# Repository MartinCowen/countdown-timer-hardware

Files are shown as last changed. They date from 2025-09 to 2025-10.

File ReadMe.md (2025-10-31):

# Child-friendly Countdown Timer  
Electronic PCB and Front Panel to fit Hammond RL6655, designed in Kicad 9.0

## Main components
 - STM32C031C6: Cortex-M0+, 32kB flash, 12kB RAM, 45 IOs
 - 0.8 inch 7-segment displays SA08-11SURKWA
 - C&K D6 buttons
 - USB micro powered from a battery pack, 0.6mA in sleep.

## PCB parameters
Two layers, mix of surface mount and through hole components, ground plane fill.

## Bill of Materials
SMT Part numbers for LCSC (JLC) 
Through hole, SMTs not available at LCSC and mechanical parts from RS or Mouser.

## Front Panel
PCB with black solder mask, white silkscreen, cutouts for displays, LEDs, buttons, mounting holes. Replaces front panel on RL6655, main PCB is mounted behind it.

## Additional components needed
 - Either a 5V 0.5A PSU (phone charger) or portable battery with USB output
 - USB A to USB micro short cable for the portable battery
 - Cable ties to hold battery back to back of PCB
 - optional: Display filter material, 40x100mm, < 1mm thick.
 - for programming: STLINK-V3MINIE with ribbon cable from [STM32C0316-DK](https://www.st.com/en/evaluation-tools/stm32c0316-dk.html)
 - for programming: USB C cable to your laptop (USB C or USB A) from the STLINK

## Firmware
[Firmware in C for STM32C031C6](https://github.com/MartinCowen/countdown-timer-firmware) built in STM32CubeIDE

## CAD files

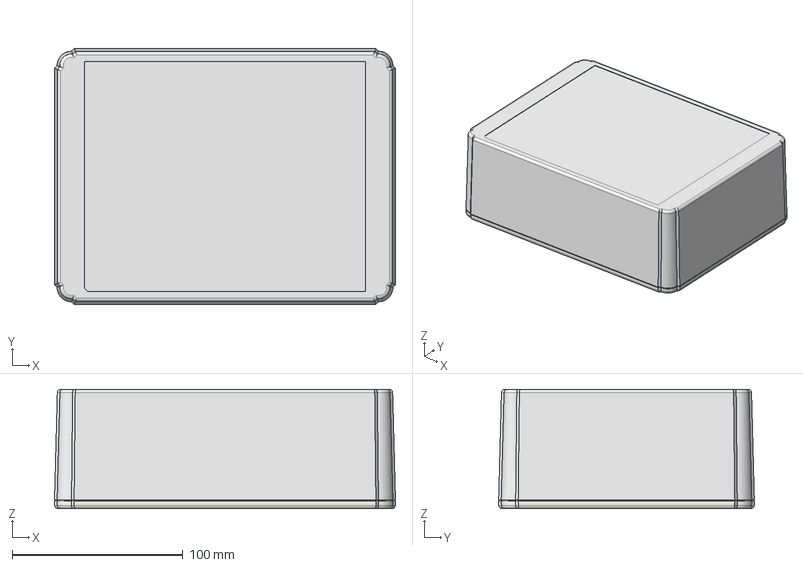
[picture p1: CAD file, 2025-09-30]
frontpanel_pcb/RL6655.stp
200.0 x 150.0 x 70.0 mm
6655B
(screw M2.6X 20mm FH) x 4

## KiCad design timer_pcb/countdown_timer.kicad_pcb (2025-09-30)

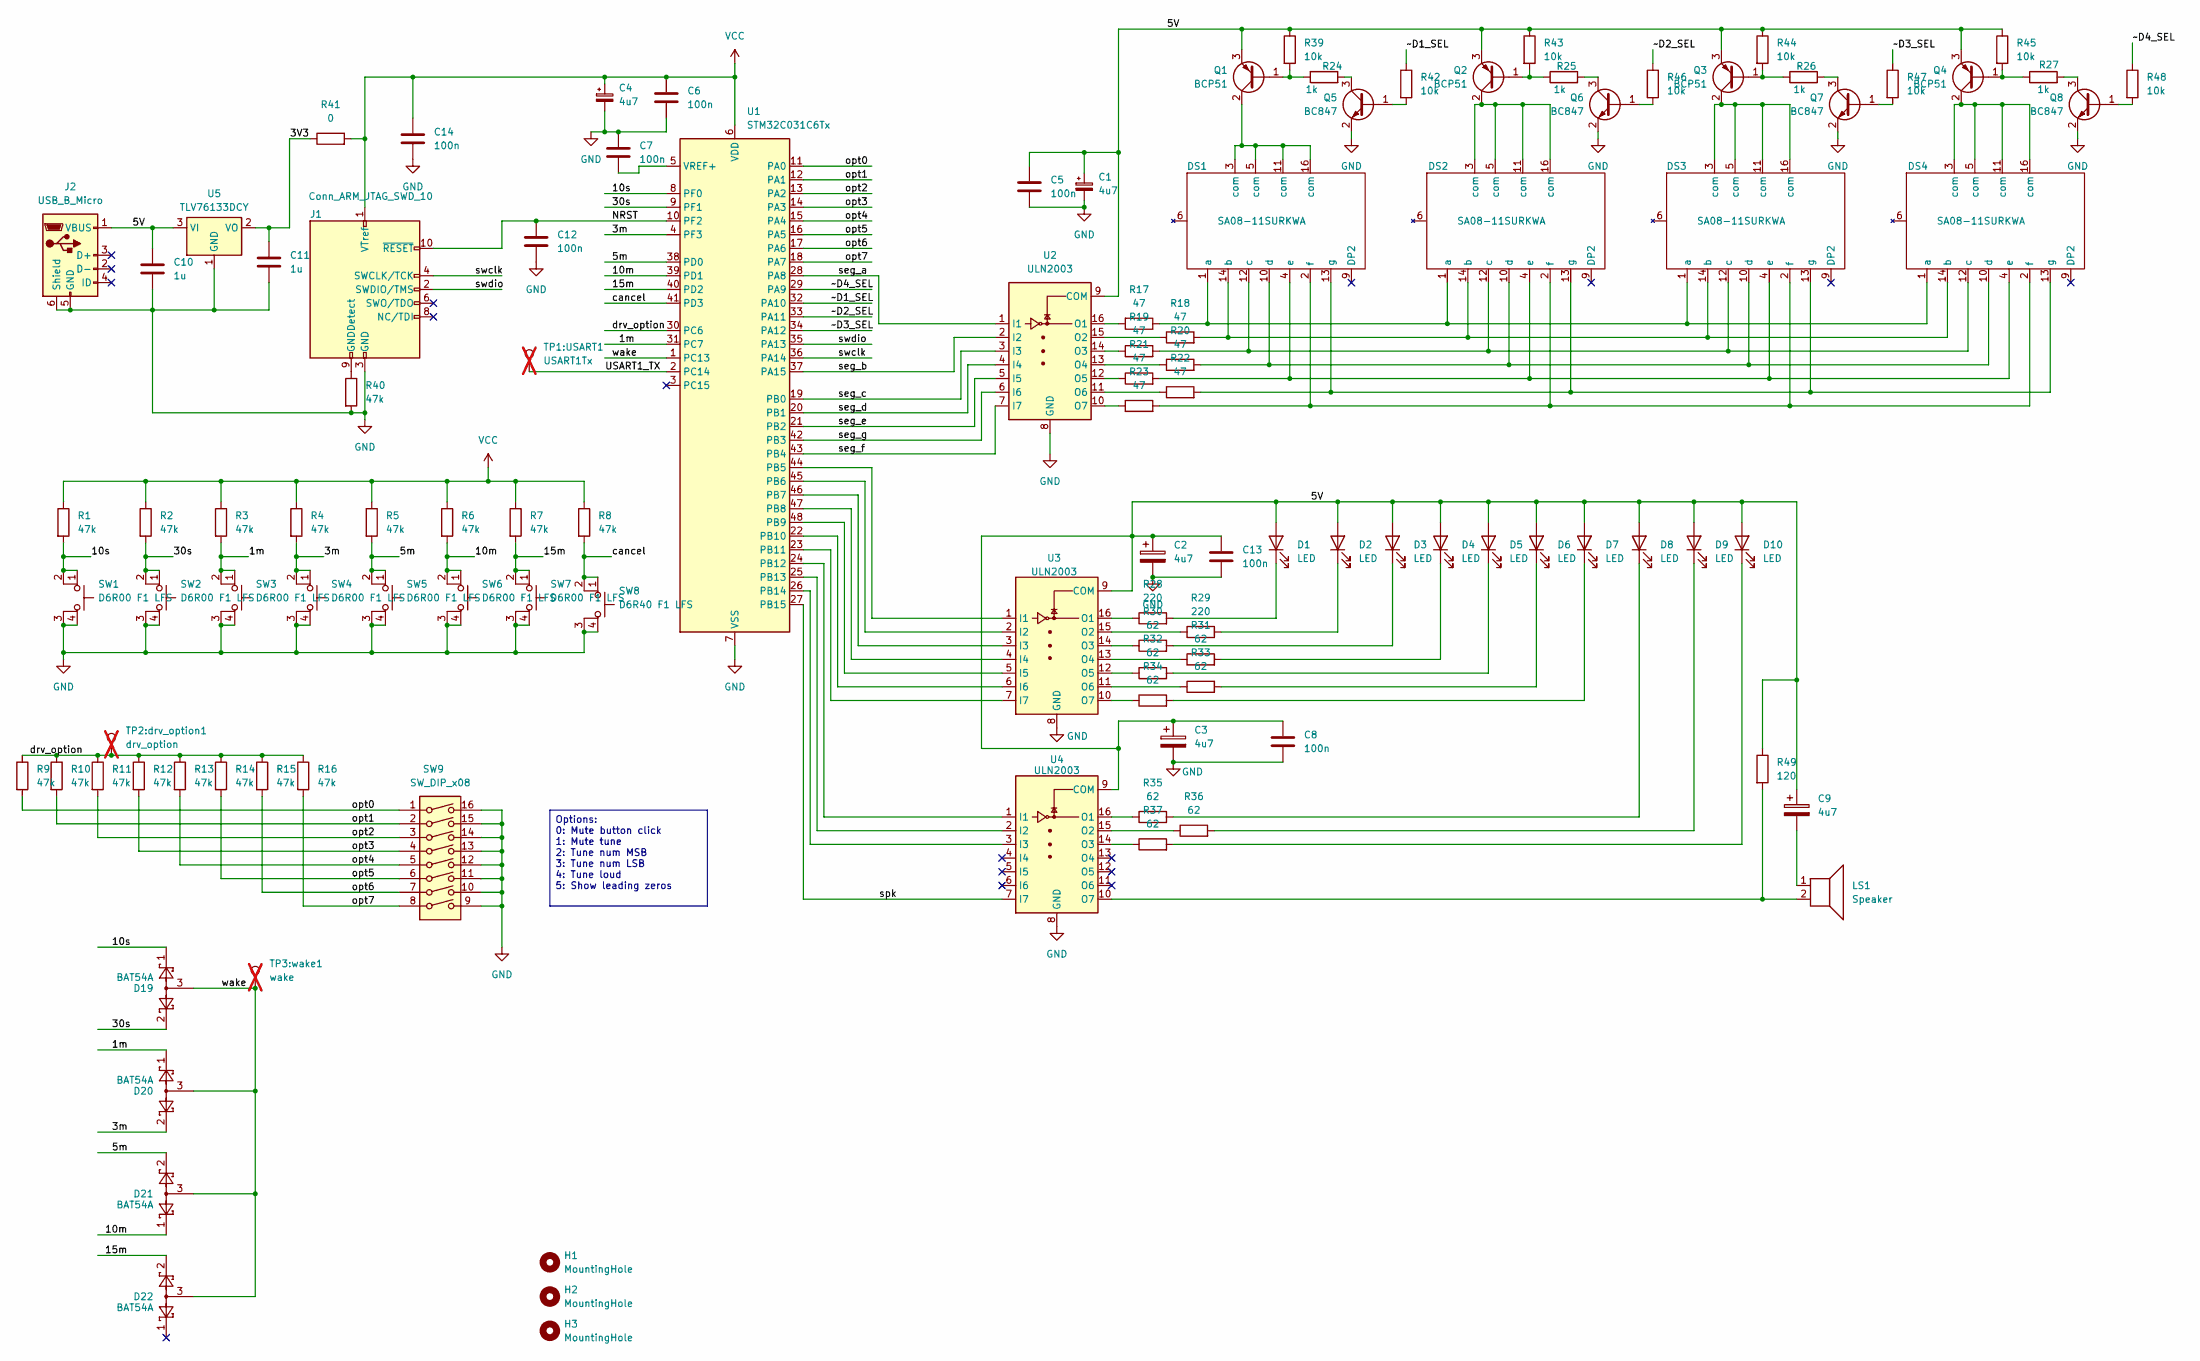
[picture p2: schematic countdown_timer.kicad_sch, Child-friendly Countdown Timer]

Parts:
C1, C2, C3, C4, C9: 4u7; CP_Elec_4x5.4; LCSC C59949
C5, C6, C7, C8, C12, C13, C14: 100n; C_0805_2012Metric; LCSC C49678
C10, C11: 1u; C_0805_2012Metric; LCSC C24123
D1, D2, D3, D4, D5, D6, D7, D8, D9, D10: LED; LED_D5.0mm_FlatTop; LCSC DNP
D19, D20, D21, D22: BAT54A; SOT-323_SC-70; LCSC C77317
DS1, DS2, DS3, DS4: SA08-11SURKWA; LCSC DNP
H1, H2, H3: MountingHole; ToolingHole_1.152mm; LCSC DNP
J1: Conn_ARM_JTAG_SWD_10; PinHeader_2x05_P1.27mm_Vertical_SMD; LCSC C5155080
J2: USB_B_Micro; USB_Micro-B_Amphenol_10118194-0001LF_Horizontal; LCSC C132563
LS1: Speaker; CMS-151504-SMT-TR; LCSC DNP
Q1, Q2, Q3, Q4: BCP51; SOT-223-3_TabPin2; LCSC C41375111
Q5, Q6, Q7, Q8: BC847; SOT-323_SC-70; LCSC C8659
R1, R2, R3, R4, R5, R6, R7, R8, R9, R10, R11, R12, R13, R14, R15, R16, R40: 47k; R_0805_2012Metric; LCSC C17713
R17, R18, R19, R20, R21, R22, R23: 47; R_0805_2012Metric; LCSC C17714
R24, R25, R26, R27: 1k; R_0805_2012Metric; LCSC C17513
R28, R29: 220; R_0805_2012Metric; LCSC C17557
R30, R31, R32, R33, R34, R35, R36, R37: 62; R_0805_2012Metric; LCSC C17557
R39, R42, R43, R44, R45, R46, R47, R48: 10k; R_0805_2012Metric; LCSC C17414
R41: 0; R_0805_2012Metric; LCSC C17477
R49: 120; R_0805_2012Metric; LCSC C17437
SW1, SW2, SW3, SW4, SW5, SW6, SW7: D6R00 F1 LFS; CK_D6; LCSC C221608
SW8: D6R40 F1 LFS; CK_D6; LCSC C668538
SW9: SW_DIP_x08; DIP-16_W7.62mm; LCSC C108707
TP1:USART1: USART1Tx; TestPoint_Pad_D1.5mm; LCSC DNP; not fitted
TP2:drv_option1: drv_option; TestPoint_Pad_D1.5mm; LCSC DNP; not fitted
TP3:wake1: wake; TestPoint_Pad_D1.5mm; LCSC DNP; not fitted
U1: STM32C031C6Tx; LQFP-48_7x7mm_P0.5mm; LCSC C5456218
U2, U3, U4: ULN2003; SOIC-16_3.9x9.9mm_P1.27mm; LCSC C7512
U5: TLV76133DCY; SOT-223-3_TabPin2; LCSC C7527500

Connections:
/1m: D20.1, R3.2, SW3.1, SW3.2, U1.31 (PC7)
/3V3: C11.1, R41.1, U5.2 (VO)
/3m: D20.2, R4.2, SW4.1, SW4.2, U1.4 (PF3)
/5V: C1.1, C2.1, C3.1, C5.1, C8.1, C9.1, C10.1, C13.1, D1.2 (A), D2.2 (A), D3.2 (A), D4.2 (A), D5.2 (A), D6.2 (A), D7.2 (A), D8.2 (A), D9.2 (A), D10.2 (A), J2.1 (VBUS), Q1.3 (E), Q2.3 (E), Q3.3 (E), Q4.3 (E), R39.1, R43.1, R44.1, R45.1, R49.1, U2.9 (COM), U3.9 (COM), U4.9 (COM), U5.3 (VI)
/5m: D21.2, R5.2, SW5.1, SW5.2, U1.38 (PD0)
/10m: D21.1, R6.2, SW6.1, SW6.2, U1.39 (PD1)
/10s: D19.1, R1.2, SW1.1, SW1.2, U1.8 (PF0)
/15m: D22.2, R7.2, SW7.1, SW7.2, U1.40 (PD2)
/30s: D19.2, R2.2, SW2.1, SW2.2, U1.9 (PF1)
/NRST: C12.1, J1.10 (~RESET), U1.10 (PF2)
/USART1_TX: TP1:USART1.1, U1.2 (PC14)
/cancel: R8.2, SW8.1, SW8.2, U1.41 (PD3)
/drv_option: R9.1, R10.1, R11.1, R12.1, R13.1, R14.1, R15.1, R16.1, TP2:drv_option1.1, U1.30 (PC6)
/opt0: R9.2, SW9.1, U1.11 (PA0)
/opt1: R10.2, SW9.2, U1.12 (PA1)
/opt2: R11.2, SW9.3, U1.13 (PA2)
/opt3: R12.2, SW9.4, U1.14 (PA3)
/opt4: R13.2, SW9.5, U1.15 (PA4)
/opt5: R14.2, SW9.6, U1.16 (PA5)
/opt6: R15.2, SW9.7, U1.17 (PA6)
/opt7: R16.2, SW9.8, U1.18 (PA7)
/seg_a: U1.28 (PA8), U2.1 (I1)
/seg_b: U1.37 (PA15), U2.2 (I2)
/seg_c: U1.19 (PB0), U2.3 (I3)
/seg_d: U1.20 (PB1), U2.4 (I4)
/seg_e: U1.21 (PB2), U2.5 (I5)
/seg_f: U1.43 (PB4), U2.7 (I7)
/seg_g: U1.42 (PB3), U2.6 (I6)
/spk: U1.27 (PB15), U4.7 (I7)
/swclk: J1.4 (SWCLK/TCK), U1.36 (PA14)
/swdio: J1.2 (SWDIO/TMS), U1.35 (PA13)
/wake: D19.3, D20.3, D21.3, D22.3, TP3:wake1.1, U1.1 (PC13)
/~D1_SEL: R42.1, U1.32 (PA10)
/~D2_SEL: R46.1, U1.33 (PA11)
/~D3_SEL: R47.1, U1.34 (PA12)
/~D4_SEL: R48.1, U1.29 (PA9)
GND: C1.2, C2.2, C3.2, C4.2, C5.2, C6.2, C7.1, C8.2, C10.2, C11.2, C12.2, C13.2, C14.2, J1.3 (GND), J1.5 (GND), J2.5 (GND), J2.6 (Shield), Q5.2 (E), Q6.2 (E), Q7.2 (E), Q8.2 (E), R40.2, SW1.3 (K), SW1.4 (A), SW2.3 (K), SW2.4 (A), SW3.3 (K), SW3.4 (A), SW4.3 (K), SW4.4 (A), SW5.3 (K), SW5.4 (A), SW6.3 (K), SW6.4 (A), SW7.3 (K), SW7.4 (A), SW8.3 (K), SW8.4 (A), SW9.9, SW9.10, SW9.11, SW9.12, SW9.13, SW9.14, SW9.15, SW9.16, U1.7 (VSS), U2.8 (GND), U3.8 (GND), U4.8 (GND), U5.1 (GND)
unnamed: C9.2, LS1.1
unnamed: D1.1 (K), R28.2
unnamed: D2.1 (K), R29.2
unnamed: D3.1 (K), R30.2
unnamed: D4.1 (K), R31.2
unnamed: D5.1 (K), R32.2
unnamed: D6.1 (K), R33.2
unnamed: D7.1 (K), R34.2
unnamed: D8.1 (K), R35.2
unnamed: D9.1 (K), R36.2
unnamed: D10.1 (K), R37.2
unnamed: DS1.1 (a), DS2.1 (a), DS3.1 (a), DS4.1 (a), R17.1
unnamed: DS1.14 (b), DS2.14 (b), DS3.14 (b), DS4.14 (b), R18.2
unnamed: DS1.12 (c), DS2.12 (c), DS3.12 (c), DS4.12 (c), R19.2
unnamed: DS1.10 (d), DS2.10 (d), DS3.10 (d), DS4.10 (d), R20.2
unnamed: DS1.4 (e), DS2.4 (e), DS3.4 (e), DS4.4 (e), R21.2
unnamed: DS1.2 (f), DS2.2 (f), DS3.2 (f), DS4.2 (f), R23.2
unnamed: DS1.13 (g), DS2.13 (g), DS3.13 (g), DS4.13 (g), R22.2
unnamed: J1.9 (GNDDetect), R40.1
unnamed: Q1.1 (B), R24.1, R39.2
unnamed: DS1.3 (com), DS1.5 (com), DS1.11 (com), DS1.16 (com), Q1.2 (C)
unnamed: Q2.1 (B), R25.1, R43.2
unnamed: DS2.3 (com), DS2.5 (com), DS2.11 (com), DS2.16 (com), Q2.2 (C)
unnamed: Q3.1 (B), R26.1, R44.2
unnamed: DS3.3 (com), DS3.5 (com), DS3.11 (com), DS3.16 (com), Q3.2 (C)
unnamed: Q4.1 (B), R27.1, R45.2
unnamed: DS4.3 (com), DS4.5 (com), DS4.11 (com), DS4.16 (com), Q4.2 (C)
unnamed: Q5.1 (B), R42.2
unnamed: Q5.3 (C), R24.2
unnamed: Q6.1 (B), R46.2
unnamed: Q6.3 (C), R25.2
unnamed: Q7.1 (B), R47.2
unnamed: Q7.3 (C), R26.2
unnamed: Q8.1 (B), R48.2
unnamed: Q8.3 (C), R27.2
unnamed: U1.44 (PB5), U3.1 (I1)
unnamed: U1.45 (PB6), U3.2 (I2)
unnamed: U1.46 (PB7), U3.3 (I3)
unnamed: U1.47 (PB8), U3.4 (I4)
unnamed: U1.48 (PB9), U3.5 (I5)
unnamed: U1.22 (PB10), U3.6 (I6)
unnamed: U1.23 (PB11), U3.7 (I7)
unnamed: U1.24 (PB12), U4.1 (I1)
unnamed: U1.25 (PB13), U4.2 (I2)
unnamed: U1.26 (PB14), U4.3 (I3)
unnamed: C7.2, U1.5 (VREF+)
unnamed: R17.2, U2.16 (O1)
unnamed: R18.1, U2.15 (O2)
unnamed: R19.1, U2.14 (O3)
unnamed: R20.1, U2.13 (O4)
unnamed: R21.1, U2.12 (O5)
unnamed: R22.1, U2.11 (O6)
unnamed: R23.1, U2.10 (O7)
unnamed: R28.1, U3.16 (O1)
unnamed: R29.1, U3.15 (O2)
unnamed: R30.1, U3.14 (O3)
unnamed: R31.1, U3.13 (O4)
unnamed: R32.1, U3.12 (O5)
unnamed: R33.1, U3.11 (O6)
unnamed: R34.1, U3.10 (O7)
unnamed: R35.1, U4.16 (O1)
unnamed: R36.1, U4.15 (O2)
unnamed: R37.1, U4.14 (O3)
unnamed: LS1.2, R49.2, U4.10 (O7)
VCC: C4.1, C6.1, C14.1, J1.1 (VTref), R1.1, R2.1, R3.1, R4.1, R5.1, R6.1, R7.1, R8.1, R41.2, U1.6 (VDD)

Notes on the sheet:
Options: 0: Mute button click 1: Mute tune 2: Tune num MSB 3: Tune num LSB 4: Tune loud 5: Show leading zeros

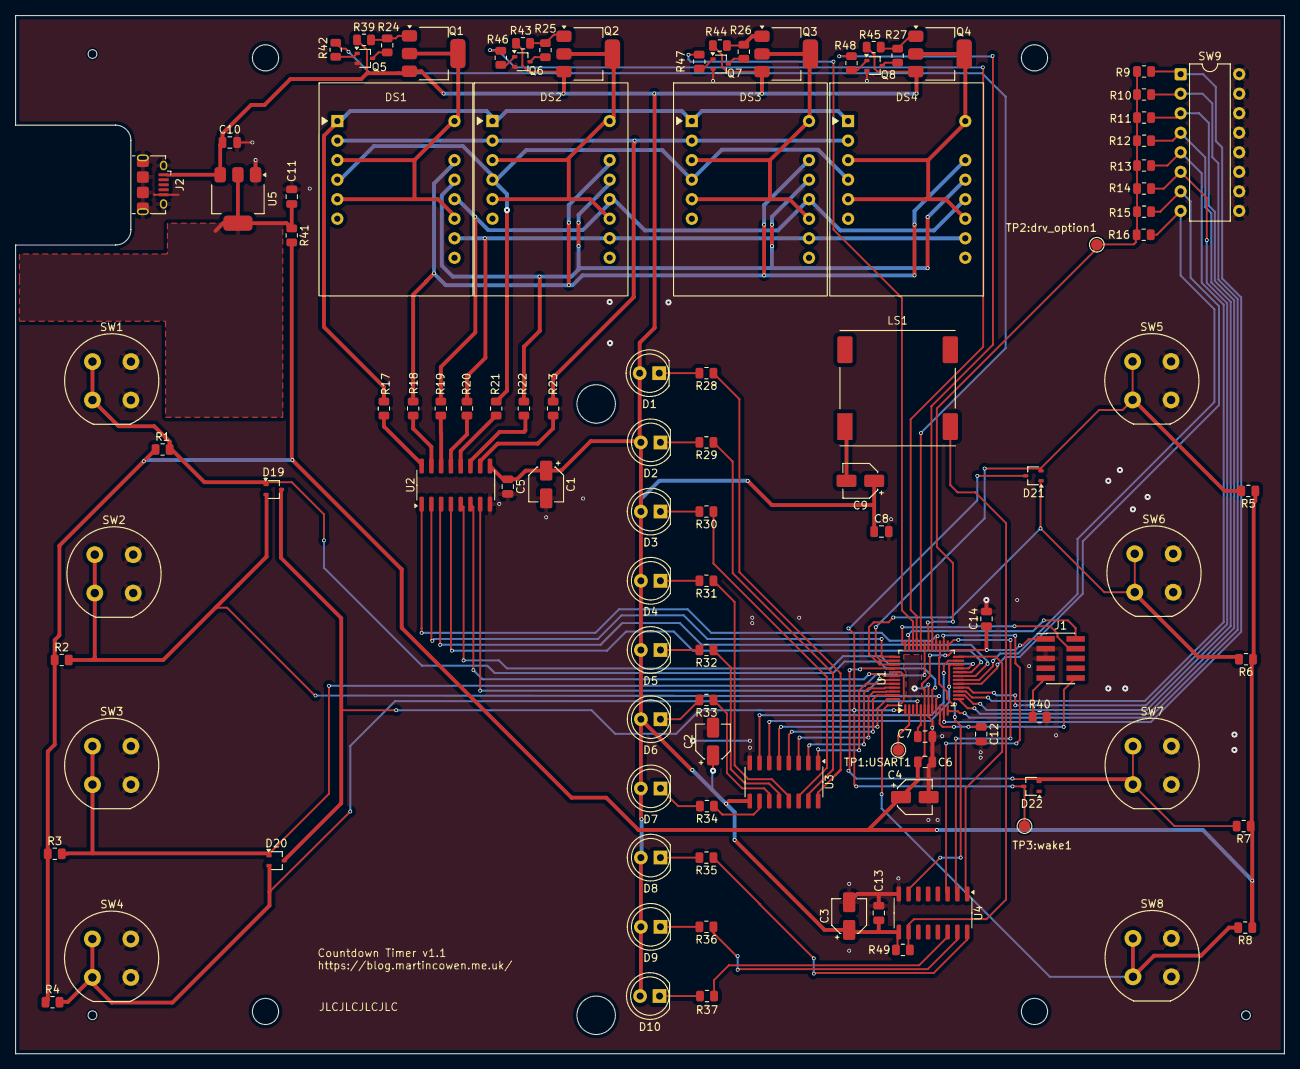
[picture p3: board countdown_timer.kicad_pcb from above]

Board: 2 copper layers, 165.0 x 135.0 mm, 111 parts (0 on the bottom side), 102 nets.
